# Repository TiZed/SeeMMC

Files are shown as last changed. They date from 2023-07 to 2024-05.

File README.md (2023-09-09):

## SeeMMC - A SD-Card adaptor for eMMC ICs

A small project to connect onboard eMMC ICs to an SD-Card slot.

The adaptor includes a level translator and 1.8V supply, to prevent damage to other board components.

This will only work for boards that have accessible eMMC signals, and can prevent onboard CPU from intervening.

To fit in a SD card slot, this design has to be manufactured with a PCB thickness of 1.2mm, not the default 1.6mm.

Successfully manufactured and tested, managed to extract the FW of a Samsung TV.

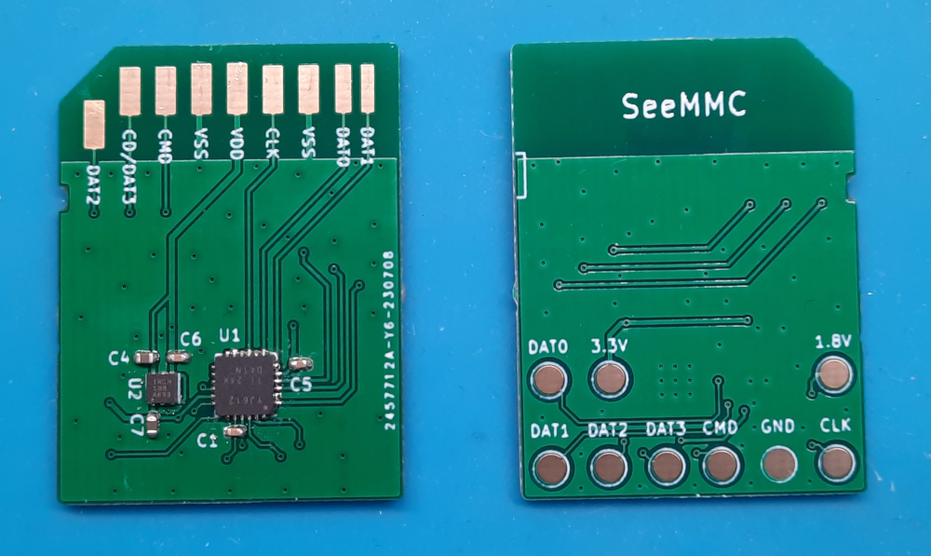
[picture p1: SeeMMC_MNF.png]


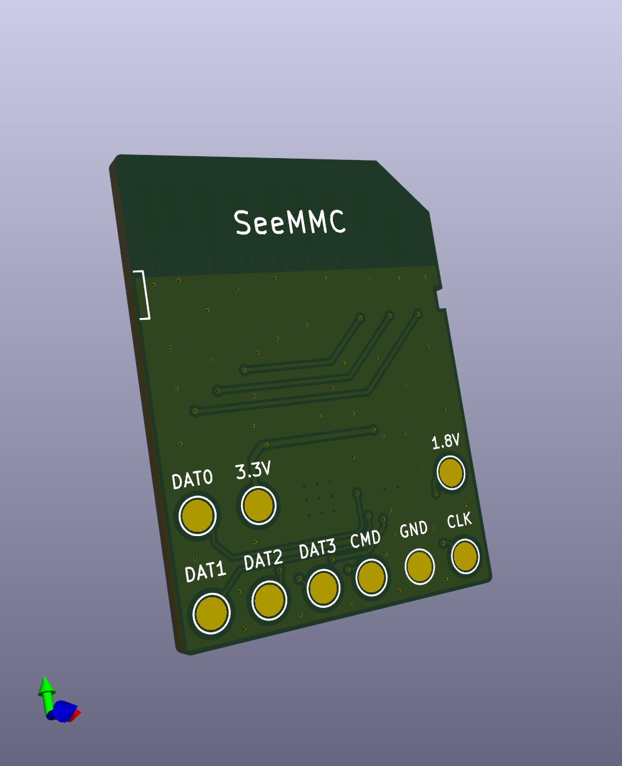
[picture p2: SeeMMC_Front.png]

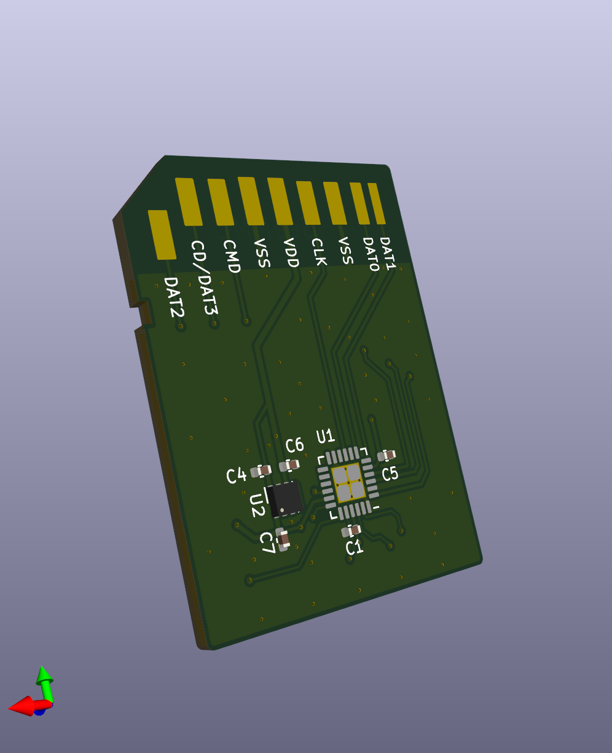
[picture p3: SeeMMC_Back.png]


---
<br />This work is licensed under a <a rel="license" href="http://creativecommons.org/licenses/by-nc-sa/4.0/">Creative Commons Attribution-NonCommercial-ShareAlike 4.0 International License</a>.

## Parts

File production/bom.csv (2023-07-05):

Designator | Footprint | Quantity | Value | LCSC Part #
C1, C5, C6 | 0402 | 3 | 0.1uF
C4, C7 | 0402 | 2 | 2.2uF
J1 | SD_Card_Layout | 1 | SD_Card
TP1 | TestPoint_Pad_D2.0mm | 1 | DAT0
TP2 | TestPoint_Pad_D2.0mm | 1 | DAT1
TP3 | TestPoint_Pad_D2.0mm | 1 | DAT2
TP4 | TestPoint_Pad_D2.0mm | 1 | DAT3
TP5 | TestPoint_Pad_D2.0mm | 1 | CMD
TP6 | TestPoint_Pad_D2.0mm | 1 | 3.3V
TP7 | TestPoint_Pad_D2.0mm | 1 | CLK
TP8 | TestPoint_Pad_D2.0mm | 1 | GND
TP9 | TestPoint_Pad_D2.0mm | 1 | 1.8V
U1 | WQFN-24-1EP_4x4mm_P0.5mm_EP2.45x2.45mm_ThermalVias | 1 | TXS02612RTWR
U2 | WSON-6-1EP_2x2mm_P0.65mm_EP1x1.6mm_ThermalVias | 1 | TPS7A1118PDRV

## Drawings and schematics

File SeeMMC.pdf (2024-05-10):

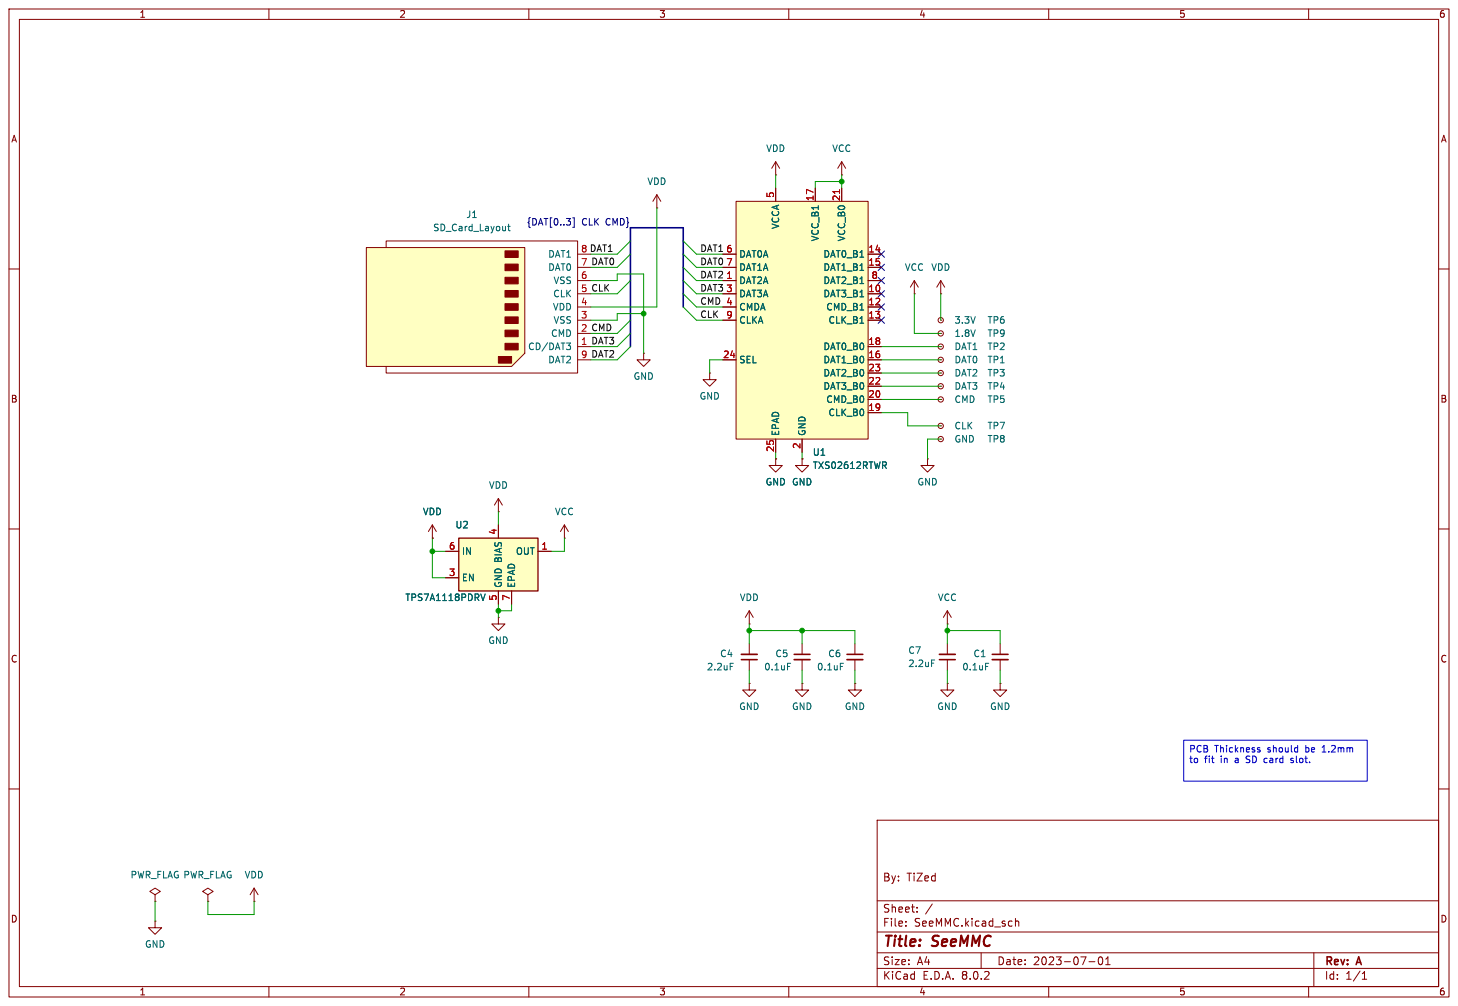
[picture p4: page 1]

2 CMD_B0 20 VCC_B0 21 DAT3_B0 22 DAT2_B0 23 SEL 24 EPAD 25 DAT3A 3 CMDA 4 VCCA

to fit in a SD card slot. U1 TXS02612RTWR

File: SeeMMC.kicad_sch Sheet: / By: TiZed GND

PCB Thickness should be 1.2mm

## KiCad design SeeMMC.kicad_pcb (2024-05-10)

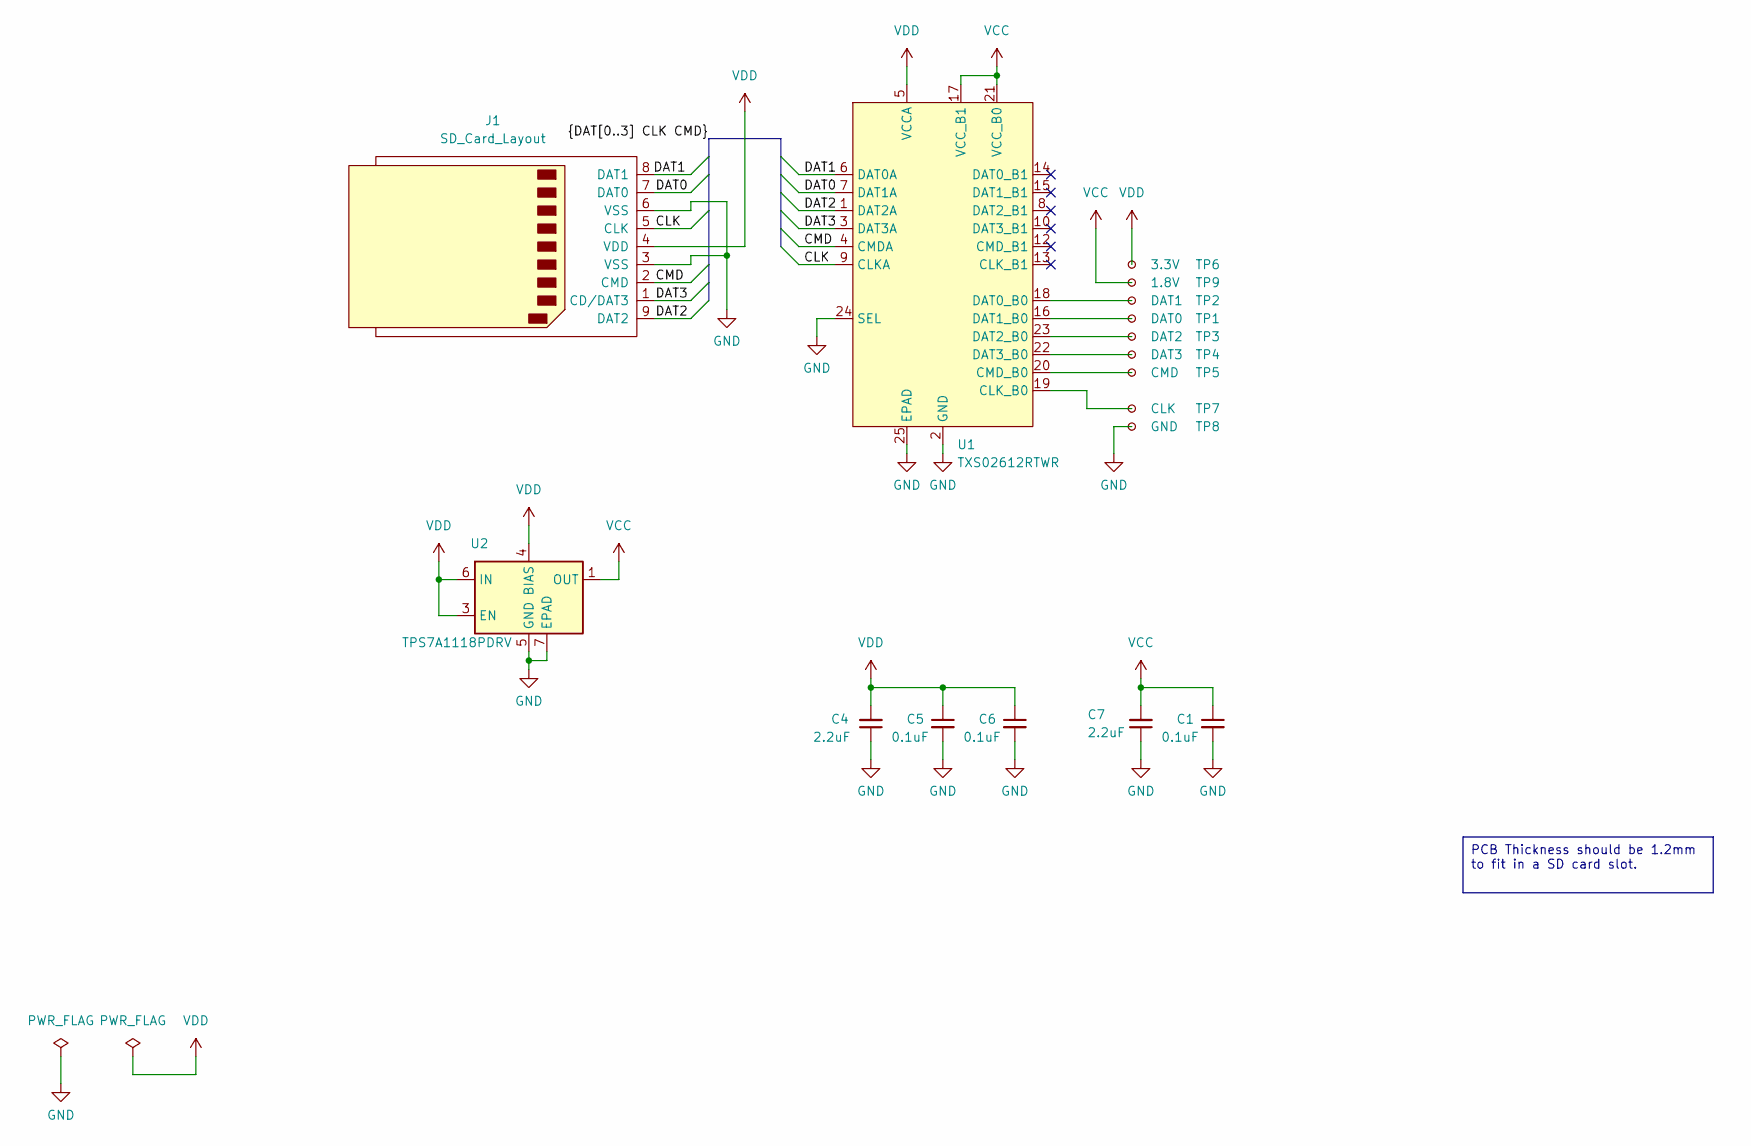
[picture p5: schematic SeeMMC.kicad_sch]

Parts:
C1, C5, C6: 0.1uF; C_0402_1005Metric
C4, C7: 2.2uF; C_0402_1005Metric
J1: SD_Card_Layout
TP1: DAT0; TestPoint_Pad_D2.0mm
TP2: DAT1; TestPoint_Pad_D2.0mm
TP3: DAT2; TestPoint_Pad_D2.0mm
TP4: DAT3; TestPoint_Pad_D2.0mm
TP5: CMD; TestPoint_Pad_D2.0mm
TP6: 3.3V; TestPoint_Pad_D2.0mm
TP7: CLK; TestPoint_Pad_D2.0mm
TP8: GND; TestPoint_Pad_D2.0mm
TP9: 1.8V; TestPoint_Pad_D2.0mm
U1: TXS02612RTWR; WQFN-24-1EP_4x4mm_P0.5mm_EP2.45x2.45mm_ThermalVias
U2: TPS7A1118PDRV; WSON-6-1EP_2x2mm_P0.65mm_EP1x1.6mm_ThermalVias

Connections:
/CLK: J1.5 (CLK), U1.9 (CLKA)
/CMD: J1.2 (CMD), U1.4 (CMDA)
/DAT0: J1.7 (DAT0), U1.7 (DAT1A)
/DAT1: J1.8 (DAT1), U1.6 (DAT0A)
/DAT2: J1.9 (DAT2), U1.1 (DAT2A)
/DAT3: J1.1 (CD/DAT3), U1.3 (DAT3A)
GND: C1.2, C4.1, C5.2, C6.2, C7.1, J1.3 (VSS), J1.6 (VSS), TP8.1, U1.2 (GND), U1.11 (GND), U1.24 (SEL), U1.25 (EPAD), U2.5 (GND), U2.7 (EPAD)
unnamed: TP7.1, U1.19 (CLK_B0)
unnamed: TP5.1, U1.20 (CMD_B0)
unnamed: TP2.1, U1.18 (DAT0_B0)
unnamed: TP1.1, U1.16 (DAT1_B0)
unnamed: TP3.1, U1.23 (DAT2_B0)
unnamed: TP4.1, U1.22 (DAT3_B0)
VCC: C1.1, C7.2, TP9.1, U1.17 (VCC_B1), U1.21 (VCC_B0), U2.1 (OUT)
VDD: C4.2, C5.1, C6.1, J1.4 (VDD), TP6.1, U1.5 (VCCA), U2.3 (EN), U2.4 (BIAS), U2.6 (IN)

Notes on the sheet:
PCB Thickness should be 1.2mm to fit in a SD card slot.

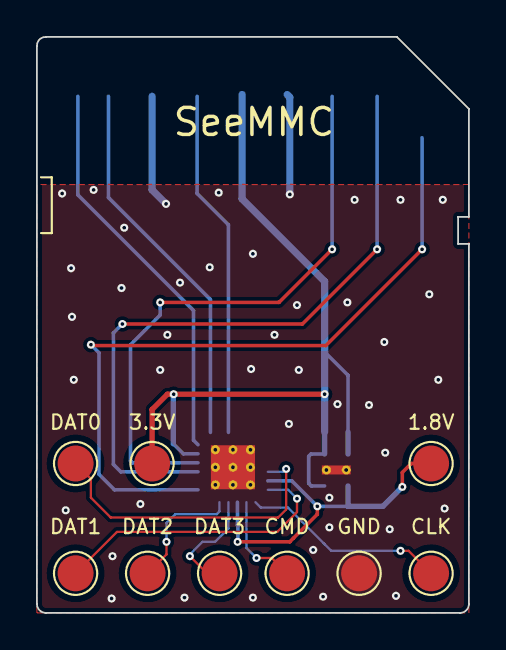
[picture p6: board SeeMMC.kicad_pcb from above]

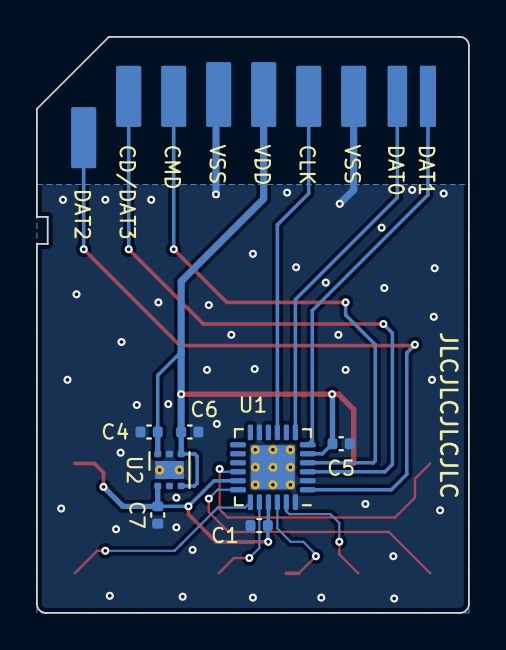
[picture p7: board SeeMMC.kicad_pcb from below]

Board: 2 copper layers, 24.0 x 32.0 mm, 17 parts (7 on the bottom side), 15 nets.

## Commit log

2023-07-05 Adding project
    [SeeMMC.kicad_pcb, SeeMMC.kicad_sch]
2023-07-05 Some cosmetic changes
    [SeeMMC.kicad_pcb]
2023-07-05 Production ready
    [SeeMMC.kicad_pcb, bom.csv, designators.csv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]
2023-07-06 Added external dimensions
    [SeeMMC.kicad_pcb]
2024-05-10 Updated KiCad version
    [SeeMMC.kicad_pcb, SeeMMC.kicad_sch]
